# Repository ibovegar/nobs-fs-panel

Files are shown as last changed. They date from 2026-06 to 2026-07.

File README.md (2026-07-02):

# Nobs Panel

A build-it-yourself switch panel for flight simulators: **8 toggle switches** wired to an
**Arduino Nano ESP32**. It plugs in over USB and shows up as a standard game controller (HID
gamepad) named **"Nobs Panel"**, recognised directly by MSFS and the Nobs app with no drivers to
install.

SW1–SW6 are 2-position (ON-ON) and SW7–SW8 are 3-position (ON-OFF-ON); each switch's two outer
terminals are reported as two buttons, for **16 buttons** total.

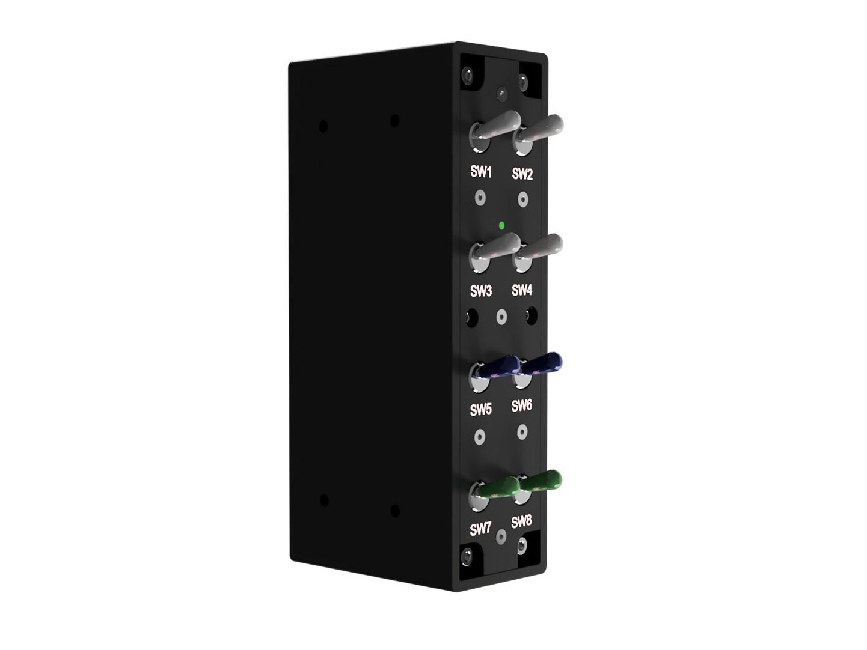
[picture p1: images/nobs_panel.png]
Nobs Panel


## Design Philosophy

**This panel is built for tactile, no-fuss control**: real mechanical toggles instead of a
touchscreen or software panel, so you always know a switch's state by feel alone, no looking
needed, which also makes it VR-friendly. Because it enumerates as a plain USB game controller,
there's nothing to install and nothing that can fall out of sync with a sim update:
* **Physical Switches, Not Software:** Every switch is a genuine toggle with a positive snap, so
  flipping it is unambiguous even without looking.
* **Driver-Free by Design:** The board presents itself as a standard HID gamepad, so MSFS and the
  Nobs app recognise it the moment it's plugged in.

## Docs

- **[Build instructions](docs/build-instructions.md)**: step-by-step assembly, photos included.
- **[Which wire goes where](docs/arduino-esp-32-wiring.md)**: the button + pin map. For a visual
  reference alongside it, see the [wiring diagram](docs/wiring-diagram.pdf).
- **[Loading the firmware](firmware/arduino_eps32_nano/README.md)**: first-time flashing and
  re-flashing, step by step.
- **[Left-mount variant](firmware/arduino_eps32_nano_left/README.md)**: a version wired for mounting
  on the **left** side of a frame, with its own [wiring map](docs/arduino-esp-32-wiring-left.md). See
  [Mounting orientation](#mounting-orientation-left-or-right) below.
- **[Setting the device ID & name](docs/board-identity.md)**: how the board names itself, how to
  rename it, and how to run several panels at once (each gets its own ID + name).
- **[Bill of materials](docs/bill-of-materials.md)**: parts list.

## Mounting orientation (left or right)

The Nobs panels are designed to mount to a 40x80 T-slot aluminium extrusion rig (e.g. a Track
Racer TR160), around the central profile assembly that holds the flight yoke or steering wheel:
**Nobs Panel** mounts to the left of the assembly, **Nobs Approach** to the right, and **Nobs
Autopilot** on top.

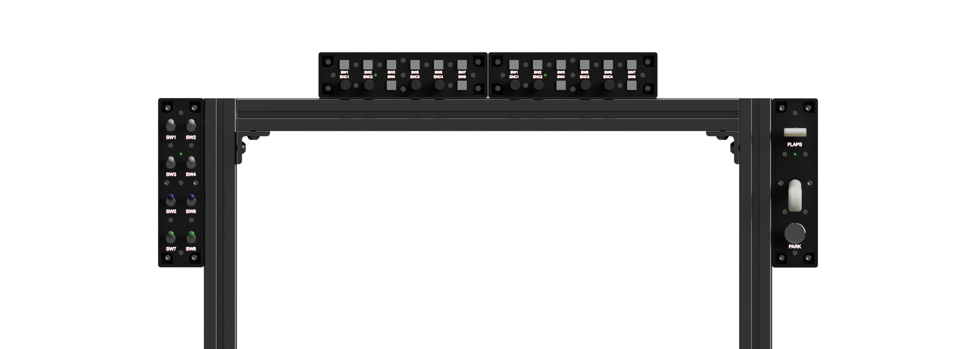
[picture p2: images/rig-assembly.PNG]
Rig assembly


The panel comes in two wiring variants so it reads correctly whichever side of a track-racer
T-profile aluminium frame you mount it on:

- **Right mount (standard):** firmware in [`firmware/arduino_eps32_nano/`](firmware/arduino_eps32_nano/),
  wiring in [arduino-esp-32-wiring.md](docs/arduino-esp-32-wiring.md).
- **Left mount:** firmware in [`firmware/arduino_eps32_nano_left/`](firmware/arduino_eps32_nano_left/),
  wiring in [arduino-esp-32-wiring-left.md](docs/arduino-esp-32-wiring-left.md).

The two are identical apart from the switch-to-pin map, which the left variant mirrors for a left
mount: the switch order is reversed (SW1/SW2 swap pin groups with SW8/SW7, and the middle four
mirror too: SW3 with SW6, SW4 with SW5), and each switch's two terminals are swapped so its up/down
isn't inverted by the rotated mount. Both present the same 16 buttons. Pick the firmware and wiring
map that match how you mounted the panel, and don't mix one variant's firmware with the other's
wiring.

Because a left and a right panel can sit in the same rig, they ship with **different default USB
IDs** from the panel's ID block so the simulator never mixes up their bindings: the right (standard)
variant is the 1st panel instance (`80F0` / "Nobs Panel"), the left variant is the 2nd
(`80F1` / "Nobs Panel 2"). See [Setting the device ID & name](#setting-the-device-id--name-in-brief)
and [docs/board-identity.md](docs/board-identity.md) for the full scheme.

## Nobs FS Companion App

The [**Nobs FS app**](https://github.com/ibovegar/nobs-fs-app) is the companion application for
communicating with and configuring this panel. It automatically detects the Nobs Panel by its USB
identity (VID `303A` / PID `80F0`), so the right device is selected even when other game
controllers are connected.

Use it to:
* **Verify wiring & test inputs:** watch every switch register live as you flip it, handy for
  confirming the build before binding anything in the sim.
* **Track multiple panels:** the Devices page lets you add extra instances of the panel, each with
  its own ID and name (see [Setting the device ID & name](#setting-the-device-id--name-in-brief)
  below), so the app and the sim can tell them apart.

See the app repository for installation and usage details: <https://github.com/ibovegar/nobs-fs-app>

## Setting the device ID & name (in brief)

The board's name and USB product ID aren't compiled in; they're stored on the board, so the same
firmware can be set up as any Nobs profile. Out of the box this is **"Nobs Panel"** (`303A` /
`80F0`). To change it, the configuration app sends a single line over the board's serial port:

```
SET_ID:80F0:Nobs Panel
```

The board saves the new name + ID, replies `OK:80F0:Nobs Panel`, and reboots so it takes effect
(`GET_ID` reads back the current values). For multiple panels, give each one the next ID in the
block, e.g. `SET_ID:80F1:Nobs Panel 2`. Full details, including the Windows name-cache refresh,
are in **[docs/board-identity.md](docs/board-identity.md)**.

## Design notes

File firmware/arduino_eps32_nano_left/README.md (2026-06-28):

# Nobs Panel: Arduino Nano ESP32 Firmware (left-mount variant)

This is the **left-mount** version of the Nobs Panel firmware, for a panel mounted on the **left**
side of a track-racer T-profile aluminium frame. It is identical to the standard (right-mount)
firmware in [`../arduino_eps32_nano/`](../arduino_eps32_nano/) except for the switch-to-pin map:
SW1/SW2 and SW7/SW8 trade pin groups so the switches read in the correct order from the left,
SW3–SW6 are unchanged. It exposes the same **16 buttons**. Wiring is in
[`docs/arduino-esp-32-wiring-left.md`](../../docs/arduino-esp-32-wiring-left.md).

Because a left panel is built to share a rig with a standard (right) panel, this firmware defaults
to the **2nd panel instance** of the panel PID block: PID **`80F1`** / name **"Nobs Panel 2"**
(the standard panel is instance 1, `80F0` / "Nobs Panel"). The two then never collide, so the
simulator keeps their bindings separate. Add it on the Nobs app's **Devices** page with the **+**
on the panel product, which tracks it as the 2nd panel. (If a left panel is your *only* panel, you
can move it onto `80F0` / "Nobs Panel" with the config app.) See
[`docs/board-identity.md`](../../docs/board-identity.md) for the full ID scheme.

> Flash this sketch only if you built the panel for a **left** mount. For a standard (right) mount,
> use [`../arduino_eps32_nano/`](../arduino_eps32_nano/) instead. The two are not interchangeable:
> they expect the switches wired to different pins.

> 👍 Everything you need is in this folder. You don't edit any Arduino files. Keep
> [`build_opt.h`](./build_opt.h) next to the sketch: the IDE uses it automatically, and the build
> fails on purpose without it. Tested with the Arduino ESP32 board package `2.0.18-arduino.5`.

## One-time setup

1. Install the **Arduino IDE** (free, from arduino.cc).
2. Add the board: **Tools → Board → Boards Manager…**, search **Arduino ESP32 Boards**, click
   **Install** (big download). Then pick **Tools → Board → Arduino ESP32 Boards → Arduino Nano ESP32**.
3. In **Tools**, set **USB Mode → `Normal mode (TinyUSB)`** and **Pin Numbering → `By Arduino pin (default)`**.

> If the board install fails ("platform not installed"), close the IDE, reopen it **as
> administrator**, and try again.

## Flashing the first time

1. Open [`arduino_eps32_nano_left.ino`](./arduino_eps32_nano_left.ino) in the Arduino IDE.
2. Plug in the board with a **data** USB cable (not charge-only), straight into the PC.
3. Click **Upload** (the round arrow).

On a fresh board this just works. 🎉 When it's done, the board reconnects as **"Nobs Panel 2"** and
the app picks it up automatically.

## Re-flashing (after firmware is already on it)

This is **different**, and expected. Once the firmware is running, the board reports a custom USB
ID and no longer auto-enters upload mode, so a normal Upload fails with:

```
No DFU capable USB device available — exit status 74
```

Put the board into **update mode** by hand first:

1. Press the **RESET** button **twice, quickly** (like a mouse double-click, ~0.3–0.5 s apart).
2. You're in update mode when the **green LED breathes slowly in and out and stays there**.
   A quick red→blue→green flash that stops is just a normal reset; try the double-tap again.
3. With the green breathing, click **Upload** right away.
4. When it finishes, press **RESET once** to start the firmware.

> **If upload still can't find the board:** it's almost always the **cable or USB port**. Swap to
> a known-good data cable and a different port (this is the most common cause). The double-tap
> timing is the other one; keep trying the rhythm.

## Check it works

- **Nobs app:** the panel is detected automatically; flip switches and watch them light up.
- **Windows:** press `Win`, type **Set up USB game controllers**, open the device's **Properties**,
  and flip switches to see the 16 buttons react.

## Changing the board's name / ID

The name and product ID aren't compiled in; they're stored on the board, so the same firmware can
become any Nobs profile. Out of the box this variant is **"Nobs Panel 2"** (`303A` / `80F1`). The
configuration app changes it over the board's serial port. See
[`docs/board-identity.md`](../../docs/board-identity.md) for how that works and the full profile list.

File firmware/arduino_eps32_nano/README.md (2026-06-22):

# Nobs Panel: Arduino Nano ESP32 Firmware

This is the program (the "firmware") that runs on an **Arduino Nano ESP32** and turns it into a
USB game controller for Microsoft Flight Simulator. Once loaded, the board shows up to your PC and
the Nobs app as **"Nobs Panel"** with **16 buttons**: the 8 toggle switches, two buttons each
(one per position). Wiring is in [`docs/arduino-esp-32-wiring.md`](../../docs/arduino-esp-32-wiring.md).

> 👍 Everything you need is in this folder. You don't edit any Arduino files. Keep
> [`build_opt.h`](./build_opt.h) next to the sketch: the IDE uses it automatically, and the build
> fails on purpose without it. Tested with the Arduino ESP32 board package `2.0.18-arduino.5`.

## One-time setup

1. Install the **Arduino IDE** (free, from arduino.cc).
2. Add the board: **Tools → Board → Boards Manager…**, search **Arduino ESP32 Boards**, click
   **Install** (big download). Then pick **Tools → Board → Arduino ESP32 Boards → Arduino Nano ESP32**.
3. In **Tools**, set **USB Mode → `Normal mode (TinyUSB)`** and **Pin Numbering → `By Arduino pin (default)`**.

> If the board install fails ("platform not installed"), close the IDE, reopen it **as
> administrator**, and try again.

## Flashing the first time

1. Open [`arduino_eps32_nano.ino`](./arduino_eps32_nano.ino) in the Arduino IDE.
2. Plug in the board with a **data** USB cable (not charge-only), straight into the PC.
3. Click **Upload** (the round arrow).

On a fresh board this just works. 🎉 When it's done, the board reconnects as **"Nobs Panel"** and
the app picks it up automatically.

## Re-flashing (after firmware is already on it)

This is **different**, and expected. Once the firmware is running, the board reports a custom USB
ID and no longer auto-enters upload mode, so a normal Upload fails with:

```
No DFU capable USB device available — exit status 74
```

Put the board into **update mode** by hand first:

1. Press the **RESET** button **twice, quickly** (like a mouse double-click, ~0.3–0.5 s apart).
2. You're in update mode when the **green LED breathes slowly in and out and stays there**.
   A quick red→blue→green flash that stops is just a normal reset; try the double-tap again.
3. With the green breathing, click **Upload** right away.
4. When it finishes, press **RESET once** to start the firmware.

> **If upload still can't find the board:** it's almost always the **cable or USB port**. Swap to
> a known-good data cable and a different port (this is the most common cause). The double-tap
> timing is the other one; keep trying the rhythm.

## Check it works

- **Nobs app:** the panel is detected automatically; flip switches and watch them light up.
- **Windows:** press `Win`, type **Set up USB game controllers**, open the device's **Properties**,
  and flip switches to see the 16 buttons react.

## Changing the board's name / ID

The name and product ID aren't compiled in; they're stored on the board, so the same firmware can
become any Nobs profile. Out of the box it's **"Nobs Panel"** (`303A` / `80F0`). The configuration
app changes it over the board's serial port. See
[`docs/board-identity.md`](../../docs/board-identity.md) for how that works and the full profile list.

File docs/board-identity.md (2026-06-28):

# How the Board Names Itself (and How to Rename It)

This page explains, in plain language, how a Nobs board tells your PC who it is, and how you can
change that without re-installing the firmware. You don't need to understand any of this to use
the panel; it's here for the curious and for anyone setting up more than one box.

## The short version

- Every Nobs box appears to your PC as a USB game controller with a **name** (like "Nobs Panel")
  and an **ID number** (called a *Product ID*, or **PID**).
- That name and ID are **not baked into the firmware**. The board remembers them in its own
  memory, so the *same* firmware can be set up as a panel, an autopilot, or an approach box.
- Out of the box, this board is **"Nobs Panel"**. You can change it later with the configuration
  app, no re-flashing needed.

## Why each box needs its own name and ID

If you own more than one Nobs box, this matters. Microsoft Flight Simulator keeps a separate set
of button bindings for each controller, but it tells controllers apart by their **ID number**.

If two boxes shared the same ID, the simulator would treat them as the same device and **mix up
their button assignments**. Giving each box its own ID (and a clear name) keeps their controls
neatly separated, so plugging in a second or third box never disturbs the first.

Here are the standard profiles. Each product owns a small **block of IDs** so you can have several
of the same type (see below):

| If the box is a… | It should be named… | ID block |
| :--- | :--- | :--- |
| Panel | Nobs Panel | `80F0`–`80F3` |
| Autopilot | Nobs Autopilot | `80F4`–`80F7` |
| Approach | Nobs Approach | `80F8`–`80FB` |

(They all share the same *vendor* ID, `303A`; that part never changes.)

## Running several of the same type

You can use more than one of the same module (say two panels) at the same time. The catch is
they must **not** look identical to the PC, or the simulator mixes up their bindings. So each one
gets its own ID and name from its product's block:

| | Name | ID |
| :-- | :-- | :-- |
| 1st panel | Nobs Panel | `80F0` |
| 2nd panel | Nobs Panel 2 | `80F1` |
| 3rd panel | Nobs Panel 3 | `80F2` |

The first one keeps the plain name and the block's first ID (its out-of-box default). For each
extra one, give it the next ID and a numbered name with the rename step below, e.g. send
`SET_ID:80F1:Nobs Panel 2` to the second panel. In the Nobs app, open **Devices** and press **+**
on that product to start tracking the extra module. The simulator then sees "Nobs Panel" and "Nobs
Panel 2" as two separate controllers with independent bindings.

> **Left-mount panels:** the [left-mount firmware variant](../firmware/arduino_eps32_nano_left/README.md)
> is built to share a rig with a standard (right) panel, so it already ships on the **2nd** panel
> instance (`80F1` / "Nobs Panel 2") rather than `80F0`. A left + right pair therefore works out of
> the box with no renaming. If a left panel is your only panel, you can move it onto `80F0` /
> "Nobs Panel" with the rename step below.

## How to rename a board

The configuration app does this for you. Behind the scenes it just sends the board one short line
of text over its connection, for example:

```
SET_ID:80F0:Nobs Panel
```

That reads as: *"Set your ID to `80F0` and your name to `Nobs Panel`."* The board then:

1. **Saves** the new name and ID into its own memory.
2. **Confirms** it received them.
3. **Restarts itself** and comes back wearing the new name.

That restart is normal and only takes a second. The reason it's needed: a board can only announce
its identity to the PC at the moment it powers on, so it has to reboot for a new name to take
effect.

> 💡 To check what a board is currently called, the app can ask it with `GET_ID`, and the board
> replies with its stored name and ID.

## If Windows still shows the old name

Windows likes to remember names, so occasionally after a rename it'll keep showing the **old** one
in its game-controller list or in the simulator. If that happens, nudge it to take a fresh look:

1. Leave the board plugged in.
2. Right-click the **Start** button → open **Device Manager**.
3. Open the **Human Interface Devices** group.
4. Right-click your controller → **Uninstall device**.
5. Unplug the USB cable, wait a couple of seconds, and plug it back in.

Windows will then read the board's name again from scratch and show the updated one.

## Related pages

- [Which wire goes where](./arduino-esp-32-wiring.md): the button and pin map.
- [Loading the firmware](../firmware/arduino_eps32_nano/README.md): step-by-step setup, including
  the more technical details of how the identity is stored.

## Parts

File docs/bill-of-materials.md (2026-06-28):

# Bill of Materials (Shopping List)

This is the full shopping list for building one Nobs Panel: every part you need, from the
electronics to the screws. The "Manufacturer / Part Number" column lists the exact parts we used,
linked to their Mouser listing, so you can search for them or find equivalents.

A few friendly notes before you start buying:

- **Exact parts aren't mandatory.** The switches, terminal blocks, and stripboard can be swapped
  for similar parts you like or already have. The part numbers here are just what's known to work.
- **The enclosure parts (section 2) are 3D printed**: you print them yourself from the files in
  the `models/` folder, or have a print service make them.
- Quantities are for **one** panel.

## Core Electronics & Switches

| Item # | Qty | Component Description | Manufacturer / Part Number | Purpose / Application |
| :--- | :--- | :--- | :--- | :--- |
| **1.1** | 1 | Arduino Nano ESP32 (with headers) | [Arduino / ABX00083](https://no.mouser.com/ProductDetail/Arduino/ABX00083) | Main microcontroller (ESP32-S3, USB HID, VID 0x303A / PID 0x80F0) |
| **1.2** | 6 | SPDT Toggle Switch, On-On (2-position) | [Apem / 636H-2](https://no.mouser.com/ProductDetail/Apem/636H-2) | SW1–SW6 |
| **1.3** | 2 | SPDT Toggle Switch, On-Off-On (3-position) | [Apem / 639H-2](https://no.mouser.com/ProductDetail/Apem/639H-2) | SW7–SW8 |
| **1.4** | 1 | Stripboard, 50 × 80 mm | [BusBoard Prototype Systems / ST1](https://no.mouser.com/ProductDetail/BusBoard-Prototype-Systems/ST1) | Controller board carrier for the Arduino, pin headers, and terminal blocks |
| **1.5** | 2 | Female Pin Header Socket, 26-position, 2.54 mm pitch | [3M Electronic Solutions Division / 929850-01-26-RA](https://no.mouser.com/ProductDetail/3M-Electronic-Solutions-Division/929850-01-26-RA) | Sockets soldered to the stripboard to seat the Arduino Nano ESP32 |
| **1.6** | 2 | Fixed Terminal Block, 6-position, 2.54 mm pitch | [GCT / TBC05-06-1-G-G](https://no.mouser.com/ProductDetail/GCT/TBC05-06-1-G-G) | Screw-down wiring for the switch signal and ground wires |
| **1.7** | 1 | 3 mm Green LED, Diffused, 2.2 V | [Lumex / SSL-LX30FT4GD](https://no.mouser.com/ProductDetail/Lumex/SSL-LX30FT4GD?qs=7jmq9uQgtYG4HR2h%252BlgbMw%3D%3D) | Front-plate status indicator |
| **1.8** | 1 | 120 Ω Resistor, 1/4 W, ±1%, Metal Film | [KOA Speer / MFS1/4DCT52R1200F](https://no.mouser.com/ProductDetail/KOA-Speer/MFS1-4DCT52R1200F?qs=ddCg%252BR5cWn20oJHZLuYO%2FQ%3D%3D) | Current-limiting resistor for the status LED |
| **1.9** | 2 | Toggle Switch Cap, Bat Lever, Green | [NKK Switches / AT434F](https://no.mouser.com/ProductDetail/NKK-Switches/AT434F?qs=O05gvr8fLT3nXnSEPt0k3g%3D%3D) | Color-coded cap for toggle switches |
| **1.10** | 2 | Toggle Switch Cap, Bat Lever, Red | [NKK Switches / AT434C](https://no.mouser.com/ProductDetail/NKK-Switches/AT434C?qs=O05gvr8fLT2riUxsIoEfkQ%3D%3D) | Color-coded cap for toggle switches |
| **1.11** | 4 | Toggle Switch Cap, Bat Lever, White | [NKK Switches / AT434B](https://no.mouser.com/ProductDetail/NKK-Switches/AT434B?qs=O05gvr8fLT2J5h7R71L7Aw%3D%3D) | Color-coded cap for toggle switches |

## Structural & Enclosure Hardware

| Item # | Qty | Component Description | Manufacturer / Part Number | Purpose / Application |
| :--- | :--- | :--- | :--- | :--- |
| **2.1** | 1 | Enclosure Top | 3D Printed (`models/enclosure_top.step`) | Main upper housing shell |
| **2.2** | 1 | Enclosure Bottom | 3D Printed (`models/enclosure_bottom.step`) | Main lower housing base, carries the controller board |
| **2.3** | 1 | Mounting Plate | 3D Printed (`models/nobs_panel_mounting_plate.step`) | Carries the 8 toggle switches |
| **2.4** | 1 | Front Plate | 3D Printed (`models/nobs_panel_frontpanel.step`) | Visual faceplate with switch labels |
| **2.5** | 10 | M4 Heat-Set Insert | [SI (PennEngineering) / IUTB-M4](https://no.mouser.com/ProductDetail/SI/IUTB-M4) | Threaded anchors moulded into the enclosure top/bottom |
| **2.6** | 11 | M3 Heat-Set Insert | [SI (PennEngineering) / IUTB-M3](https://no.mouser.com/ProductDetail/SI/IUTB-M3) | Threaded anchors moulded into the mounting plate and front plate |
| **2.7** | 4 | M4 × 0.7, 30 mm Socket-Head Screw | — | Clamps the enclosure top and bottom halves together |
| **2.8** | 6 | M4 × 0.7, 10 mm Socket-Head Screw | — | Fastens the mounting plate to the rear of the enclosure bottom |
| **2.9** | 4 | M3 × 0.5, 8 mm Pan-Head Screw | — | Fastens the controller board to its standoffs in the enclosure bottom |
| **2.10** | 7 | M3 × 0.5, 8 mm Countersunk Screw | — | Fastens the front plate to the mounting plate, and the assembly to the enclosure |

## Connectors & Wiring

| Item # | Qty | Component Description | Manufacturer / Part Number | Purpose / Application |
| :--- | :--- | :--- | :--- | :--- |
| **3.1** | 1 | USB-C to USB-A Cable, 1.5 m to 2 m, data-sync capable | — | Connects the Arduino Nano ESP32 to your PC |
| **3.2** | 1 | Heat Shrink Tubing Assortment Pack, 1.5 mm to 3.5 mm diameters | — | Insulates soldered connections on the switch terminals |

## Tools Recommended for Assembly (Not in BOM Cost)

* **Soldering Iron & Lead-Free Rosin-Core Solder:** for attaching wires to the switch terminals
  and seating the pin headers/terminal blocks on the stripboard.
* **Wire Strippers & Flush Cutters:** for prepping the signal and ground wires.
* **Soldering Iron / Insert Tool for Heat-Set Inserts:** for pressing the brass inserts squarely
  into the 3D-printed parts.
* **Multimeter:** for testing continuity and checking for short circuits across the common ground
  loop before plugging into USB power.

## Project Costs

Rough cost estimate for a single panel, in USD. These are ballpark figures only, actual prices
vary significantly by supplier, region, and quantity, and **exclude shipping and taxes**. Several
items (heat-set inserts, screws) are sold in multi-build packs, so the per-build cost is lower if
you build more than one or already have them on hand.

| Category | Items | Estimated Cost |
| :--- | :--- | ---: |
| Microcontroller | Arduino Nano ESP32 (genuine; clones are cheaper) | $20 – $28 |
| Switches | 6 × Apem 636H-2 + 2 × Apem 639H-2 | $40 – $65 |
| Board & connectors | Stripboard, 2 × pin headers, 2 × terminal blocks, status LED | $10 – $15 |
| Fasteners | Heat-set inserts (21) and M3/M4 screws (21) | $10 – $18 |
| Enclosure (3D printed) | Filament for top, bottom, mounting plate, front plate | $5 – $15 |
| Connectors & wiring | USB-C cable, heat-shrink tubing pack | $8 – $15 |
| **Total** | | **≈ $93 – $156** |

> **Notes:**
> * The **enclosure** assumes you print the parts yourself (filament cost only). Ordering them
>   from a print service will add roughly $20 – $50.
> * This estimate doesn't include hookup wire, since it's usually bought once in bulk and reused
>   across builds.
> * Bulk/pack purchasing of the inserts, screws, and heat-shrink tubing spreads their cost across
>   multiple builds, lowering the effective per-panel total.

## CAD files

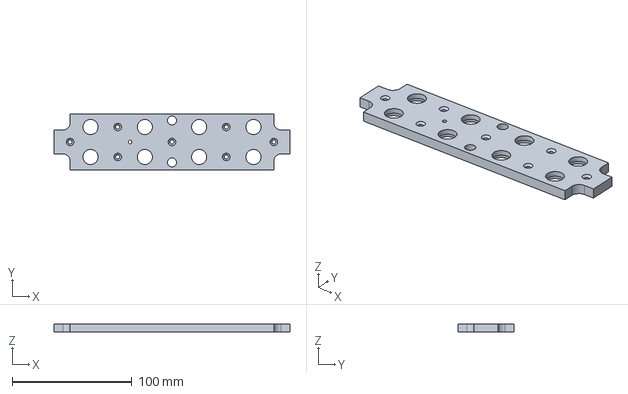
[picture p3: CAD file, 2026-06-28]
models/nobs_panel_frontpanel.step
197.0 x 47.0 x 7.00 mm

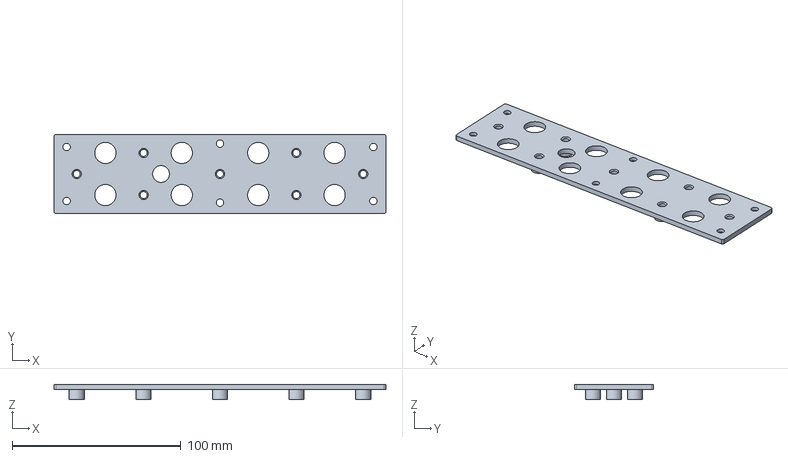
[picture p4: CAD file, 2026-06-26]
models/nobs_panel_mounting_plate.step
197.0 x 47.0 x 9.00 mm

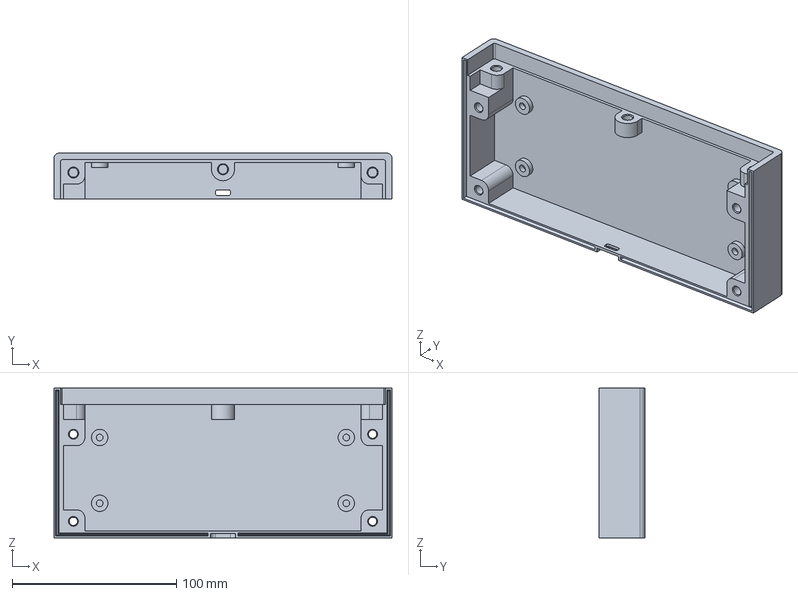
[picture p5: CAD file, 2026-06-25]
models/enclosure_top.step
205.6 x 27.8 x 91.0 mm

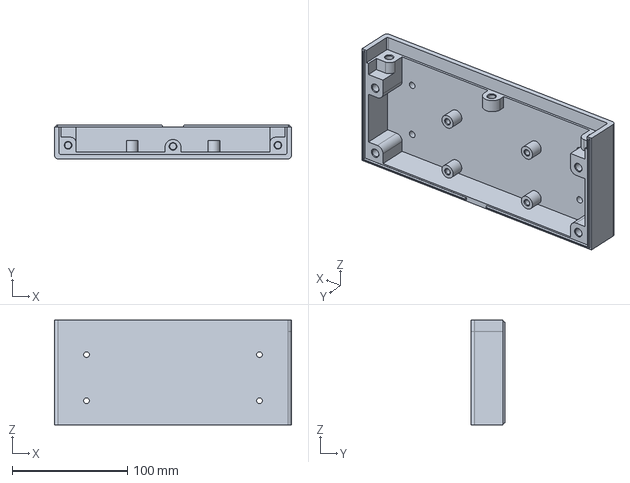
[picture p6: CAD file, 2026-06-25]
models/enclosure_bottom.step
205.6 x 29.3 x 91.0 mm

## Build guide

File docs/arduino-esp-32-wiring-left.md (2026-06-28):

# Wiring Map (Left Mount): Which Wire Goes Where

This is the wiring table for the **left-mount** version of the panel, mounted on the **left** side
of a track-racer T-profile aluminium frame. It pairs with the left firmware in
[`firmware/arduino_eps32_nano_left/`](../firmware/arduino_eps32_nano_left/). For a standard (right)
mount, use [arduino-esp-32-wiring.md](arduino-esp-32-wiring.md) and its firmware instead.

Compared with the standard wiring, the panel is **mirrored for a left mount**, which changes the
map in two ways:

1. **The switch order is reversed** so the switches read in the correct order from the left: SW1/SW2
   trade their pin groups with SW8/SW7, and the middle four mirror too (**SW3 swaps with SW6, SW4
   swaps with SW5**).
2. **Each switch's two positions are flipped.** The switch sits rotated in a left mount, so its Pin
   1 and Pin 3 terminals map to the opposite position (and HID button) than on the standard mount.
   Without this the switches would read upside down (flipping up shows as down).

The board pin each terminal connects to is the actionable column and is the same as how the switch
is physically wired; the switch types and the set of 16 HID buttons are unchanged.

This button box has **8 toggle switches**: SW1–SW6 are **ON-ON** (2-position) and SW7–SW8 are
**ON-OFF-ON** (3-position, with the center position doing nothing). Every switch has three
terminals: the two outer terminals (pin 1 and pin 3) each go to a signal pin, and the center
terminal (pin 2) goes to **GND**.

**How to read a row:** find the switch (e.g. "SW1"), look at which terminal it is ("Pin 1"), then
run a wire from that terminal to the pin listed in the board's column. Pin names like `D13` or
`A0` are printed on the board itself. Every switch's center terminal (pin 2) connects to **GND**
(ground), see the last row.

The "Virtual HID Button" column is just for reference: it's the button number the sim sees when
you flip that switch into that position. You don't wire anything for it.

> 💡 Each switch terminal has one wire to its signal pin (from this table) and the center terminal
> wires to **GND**. No resistors or extra parts needed; the firmware handles that.

| Component Group | Component Label | Hardware Connection | Arduino Nano ESP32 Pin | Virtual HID Button | Action Type |
| :--- | :--- | :--- | :--- | :--- | :--- |
| **SW1** (ON-ON) | Switch 1 | Pin 1 Terminal | **D8** | Button 2 | Position 2 |
| | Switch 1 | Pin 3 Terminal | **D7** | Button 1 | Position 1 |
| **SW2** (ON-ON) | Switch 2 | Pin 1 Terminal | **D6** | Button 4 | Position 2 |
| | Switch 2 | Pin 3 Terminal | **D5** | Button 3 | Position 1 |
| **SW3** (ON-ON) | Switch 3 | Pin 1 Terminal | **D10** | Button 6 | Position 2 |
| | Switch 3 | Pin 3 Terminal | **D9** | Button 5 | Position 1 |
| **SW4** (ON-ON) | Switch 4 | Pin 1 Terminal | **D12** | Button 8 | Position 2 |
| | Switch 4 | Pin 3 Terminal | **D11** | Button 7 | Position 1 |
| **SW5** (ON-ON) | Switch 5 | Pin 1 Terminal | **A6** | Button 10 | Position 2 |
| | Switch 5 | Pin 3 Terminal | **A7** | Button 9 | Position 1 |
| **SW6** (ON-ON) | Switch 6 | Pin 1 Terminal | **A4** | Button 12 | Position 2 |
| | Switch 6 | Pin 3 Terminal | **A5** | Button 11 | Position 1 |
| **SW7** (ON-OFF-ON) | Switch 7 | Pin 1 Terminal | **A2** | Button 14 | Position 2 |
| | Switch 7 | Pin 3 Terminal | **A3** | Button 13 | Position 1 |
| **SW8** (ON-OFF-ON) | Switch 8 | Pin 1 Terminal | **A0** | Button 16 | Position 2 |
| | Switch 8 | Pin 3 Terminal | **A1** | Button 15 | Position 1 |
| **Ground Loop** | All Switches | Pin 2 / Center Terminals | **GND** | *None* | System Ground |
| **Status LED** | Status LED | Anode, via 120 Ω resistor | **D4** | *None* | Boot/Connect Status |
| | Status LED | Cathode | **GND** | *None* | Boot/Connect Status |

> 💡 **Status LED:** wired with a 120 Ω current-limiting resistor from **D4** to **GND**. It blinks
> while the board is booting/waiting for USB enumeration, and lights steady once the host PC has
> enumerated it. (Same as the standard mount — the LED isn't affected by the left-mount pin swap.)

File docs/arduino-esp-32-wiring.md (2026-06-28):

# Wiring Map: Which Wire Goes Where

This table tells you which pin on the board each wire connects to, for the **Arduino Nano ESP32**.

> This is the **standard (right-mount)** wiring, paired with the firmware in
> [`firmware/arduino_eps32_nano/`](../firmware/arduino_eps32_nano/). If you are building the panel
> for a **left** mount, use [arduino-esp-32-wiring-left.md](arduino-esp-32-wiring-left.md) and its
> left firmware instead.

This button box has **8 toggle switches**: SW1–SW6 are **ON-ON** (2-position) and SW7–SW8 are
**ON-OFF-ON** (3-position, with the center position doing nothing). Every switch has three
terminals: the two outer terminals (pin 1 and pin 3) each go to a signal pin, and the center
terminal (pin 2) goes to **GND**.

**How to read a row:** find the switch (e.g. "SW1"), look at which terminal it is ("Pin 1"), then
run a wire from that terminal to the pin listed in the board's column. Pin names like `D13` or
`A0` are printed on the board itself. Every switch's center terminal (pin 2) connects to **GND**
(ground), see the last row.

The "Virtual HID Button" column is just for reference: it's the button number the sim sees when
you flip that switch into that position. You don't wire anything for it.

> 💡 Each switch terminal has one wire to its signal pin (from this table) and the center terminal
> wires to **GND**. No resistors or extra parts needed; the firmware handles that.

| Component Group | Component Label | Hardware Connection | Arduino Nano ESP32 Pin | Virtual HID Button | Action Type |
| :--- | :--- | :--- | :--- | :--- | :--- |
| **SW1** (ON-ON) | Switch 1 | Pin 1 Terminal | **A0** | Button 1 | Position 1 |
| | Switch 1 | Pin 3 Terminal | **A1** | Button 2 | Position 2 |
| **SW2** (ON-ON) | Switch 2 | Pin 1 Terminal | **A2** | Button 3 | Position 1 |
| | Switch 2 | Pin 3 Terminal | **A3** | Button 4 | Position 2 |
| **SW3** (ON-ON) | Switch 3 | Pin 1 Terminal | **A4** | Button 5 | Position 1 |
| | Switch 3 | Pin 3 Terminal | **A5** | Button 6 | Position 2 |
| **SW4** (ON-ON) | Switch 4 | Pin 1 Terminal | **A6** | Button 7 | Position 1 |
| | Switch 4 | Pin 3 Terminal | **A7** | Button 8 | Position 2 |
| **SW5** (ON-ON) | Switch 5 | Pin 1 Terminal | **D12** | Button 9 | Position 1 |
| | Switch 5 | Pin 3 Terminal | **D11** | Button 10 | Position 2 |
| **SW6** (ON-ON) | Switch 6 | Pin 1 Terminal | **D10** | Button 11 | Position 1 |
| | Switch 6 | Pin 3 Terminal | **D9** | Button 12 | Position 2 |
| **SW7** (ON-OFF-ON) | Switch 7 | Pin 1 Terminal | **D8** | Button 13 | Position 1 |
| | Switch 7 | Pin 3 Terminal | **D7** | Button 14 | Position 2 |
| **SW8** (ON-OFF-ON) | Switch 8 | Pin 1 Terminal | **D6** | Button 15 | Position 1 |
| | Switch 8 | Pin 3 Terminal | **D5** | Button 16 | Position 2 |
| **Ground Loop** | All Switches | Pin 2 / Center Terminals | **GND** | *None* | System Ground |
| **Status LED** | Status LED | Anode, via 120 Ω resistor | **D4** | *None* | Boot/Connect Status |
| | Status LED | Cathode | **GND** | *None* | Boot/Connect Status |

> 💡 **Status LED:** wired with a 120 Ω current-limiting resistor from **D4** to **GND**. It blinks
> while the board is booting/waiting for USB enumeration, and lights steady once the host PC has
> enumerated it.

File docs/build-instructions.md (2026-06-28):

# Nobs Panel: Build Instructions

These are the hands-on build steps for the Nobs Panel: how to build the controller board, how to
assemble the enclosure, and how to verify it before binding in the sim. For the project overview,
parts list, and device identity, see the [main README](../README.md).

> For the pin map, see [arduino-esp-32-wiring.md](arduino-esp-32-wiring.md). For a visual
> reference alongside it, see the [wiring diagram](wiring_diagram.pdf).
>
> Mounting on the **left** side of a frame instead? Use the left-mount wiring map
> ([arduino-esp-32-wiring-left.md](arduino-esp-32-wiring-left.md)) and the matching left firmware
> throughout these steps. See [Mounting orientation](../README.md#mounting-orientation-left-or-right).

## Assembly Instructions

Here's how the panel goes together, in order, with a photo of the real build at each stage.
There's soldering involved, so take your time and work in a well-lit, ventilated spot. Don't
rush; it's much easier to get each joint right the first time than to fix it later.

### Building the Controller Board

The controller board is a stripboard carrying the Arduino, pin headers, and screw-terminal blocks
for all the switch wiring.

#### Phase 1: Bare Stripboard

<p align="center">
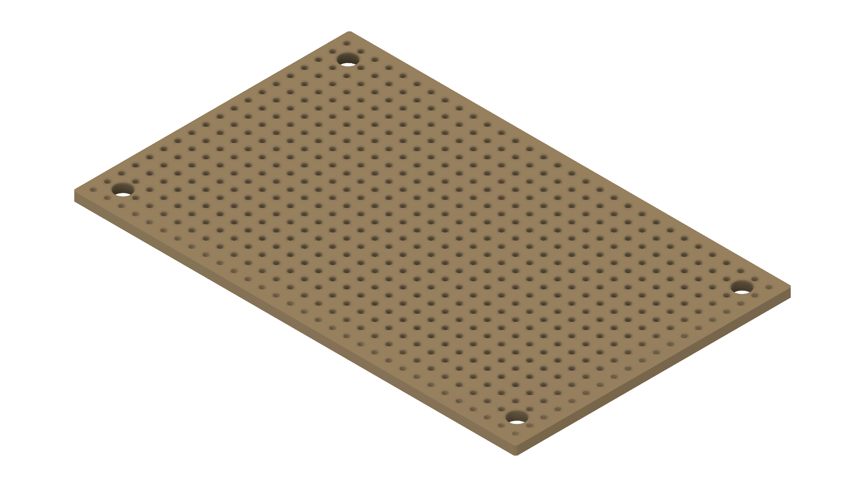
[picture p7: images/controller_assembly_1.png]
Bare stripboard
  
</p>
<br>

* **Start with the Stripboard:** This is the unmodified stripboard the rest of the controller
  board is built on. Copper strips run the full length of the board on the underside.

#### Phase 2: Mount the Pin Headers

<p align="center">
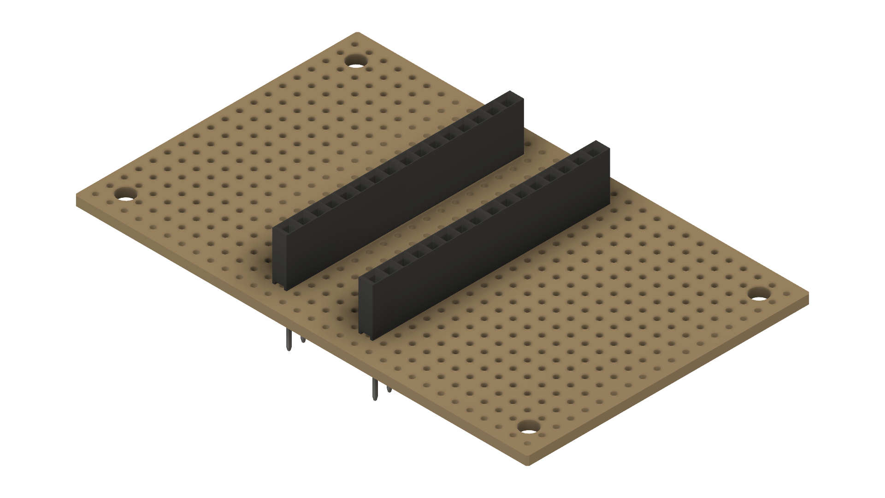
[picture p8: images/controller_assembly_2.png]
Pin headers mounted on the stripboard
  
</p>
<br>

* **Solder in the Pin Headers:** Mount the two female pin header rows that the Arduino Nano ESP32
  will plug into, spaced to match the Arduino's footprint.
* **Break the Strip Down the Middle:** The stripboard's copper strips run underneath both header
  rows, which would short the Arduino's top and bottom pin rows together. Cut or score each strip on the bottom side of the stripboard
  in the gap between the two header rows to break that connection before going further.

#### Phase 3: Mount the Terminal Blocks

<p align="center">
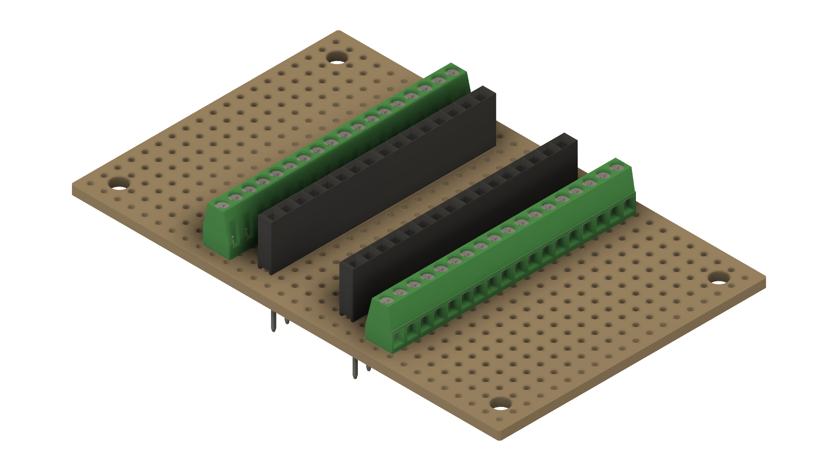
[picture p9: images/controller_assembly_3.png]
Terminal blocks mounted on the stripboard
  
</p>
<br>

* **Solder in the Terminal Blocks:** Mount the screw-terminal blocks alongside the pin headers.
  These are where each switch's signal and ground wires land, per the
  [wiring map](arduino-esp-32-wiring.md).

#### Phase 4: Add the Arduino Nano ESP32

<p align="center">
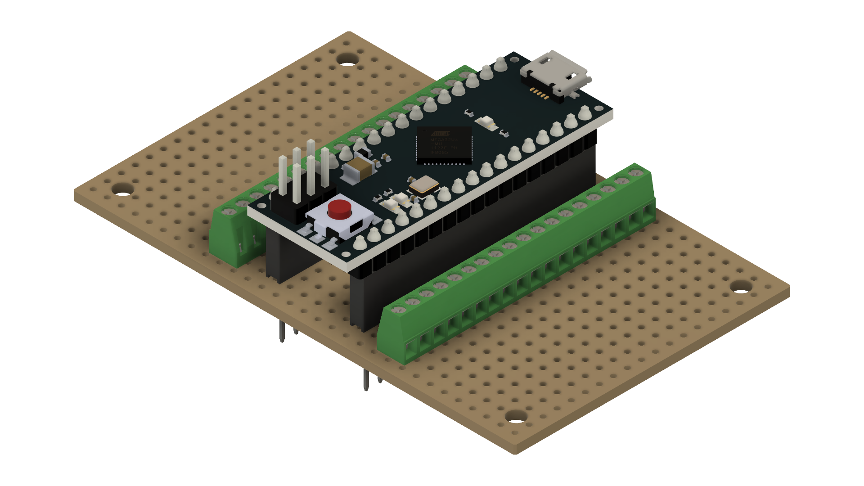
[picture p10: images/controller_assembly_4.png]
Arduino Nano ESP32 plugged into the controller board
  
</p>
<br>

* **Plug In the Arduino:** Seat the Arduino Nano ESP32 into the pin headers. The controller board
  is now complete and ready to go into the enclosure.

### Assembling the Enclosure

#### Phase 1: Heat-Set Inserts

<p align="center">
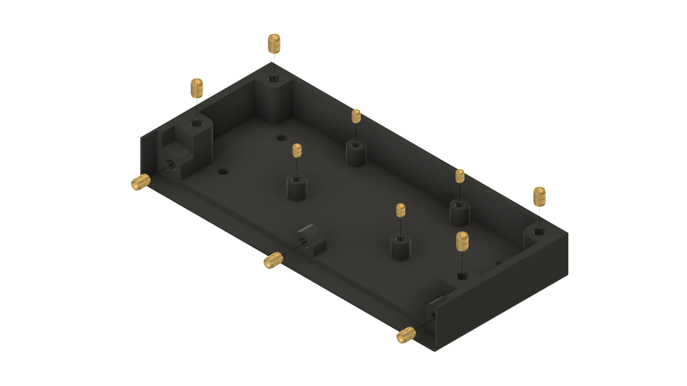
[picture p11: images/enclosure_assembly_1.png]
Heat-set inserts installed in the bottom enclosure
  
</p>
<br>

* **Press in the Inserts:** Using a soldering iron (or a dedicated insert tool) heated to the
  insert manufacturer's recommended temperature, press each heat-set insert squarely into its
  mounting post in the bottom enclosure. Go in slowly and keep the insert level: a crooked insert
  is the most common mistake here.
* **Do the Top Enclosure Too:** The top enclosure takes the same heat-set inserts in the same way.
  It isn't pictured separately; just repeat this step for it before moving on.

#### Phase 2: Mount the Controller Board to the Bottom Enclosure

<p align="center">
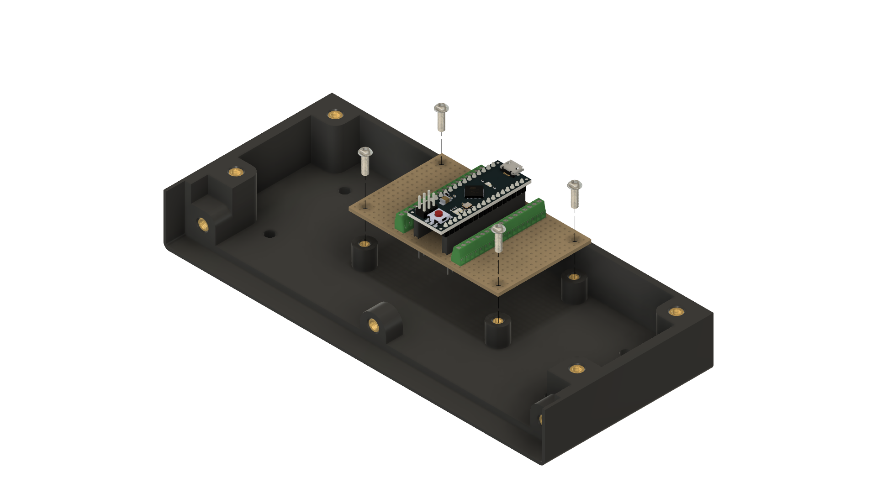
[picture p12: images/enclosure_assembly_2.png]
Controller board positioned over its mounting screws in the bottom enclosure
  
</p>
<br>

<p align="center">
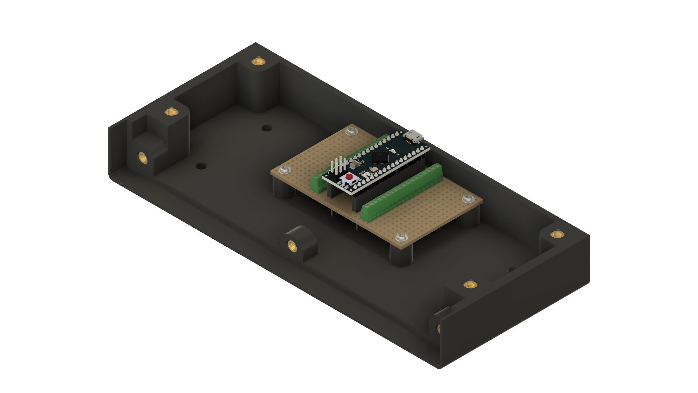
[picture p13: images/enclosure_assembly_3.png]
Controller board secured in the bottom enclosure
  
</p>
<br>

* **Secure the Controller Board:** Place the assembled controller board onto its standoffs in the
  bottom enclosure and fix it down with its mounting screws.

#### Phase 3: Heat-Set Inserts in the Mounting Plate

<p align="center">
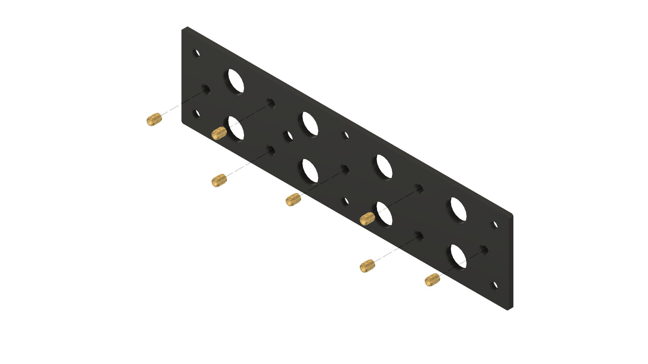
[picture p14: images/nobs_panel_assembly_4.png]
Heat-set inserts installed in the mounting plate
  
</p>
<br>

* **Press in the Inserts:** Press heat-set inserts into the mounting plate's posts the same way as
  the enclosure halves.

#### Phase 4: Mount the Switches to the Mounting Plate

<p align="center">
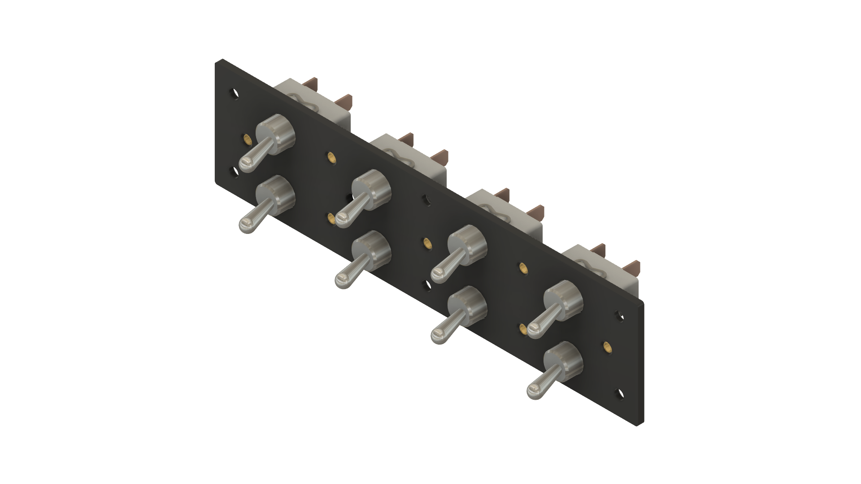
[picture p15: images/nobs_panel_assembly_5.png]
Toggle switches mounted in the mounting plate
  
</p>
<br>

* **Place the Switches:** Insert the 8 toggle switches into their cutouts in the mounting plate,
  in the layout shown, and secure each one with its included washer and hex nut, tightened firmly
  by hand. Avoid over-torquing the plastic.

#### Phase 5: Mount the Front Plate to the Mounting Plate

<p align="center">
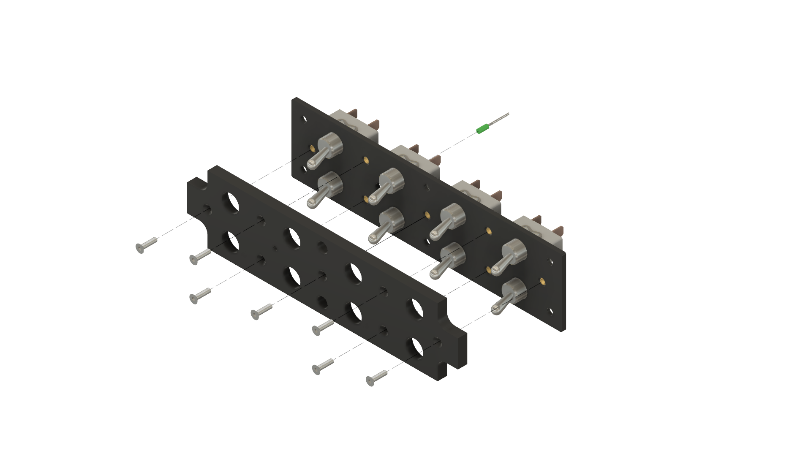
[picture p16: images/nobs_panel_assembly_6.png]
Front plate being secured over the mounted switches
  
</p>
<br>

* **Join Front Plate to Mounting Plate:** Align the front plate over the switches and secure it to
  the mounting plate with its mounting screws.

#### Phase 6: Mount the Assembly to the Enclosure

<p align="center">
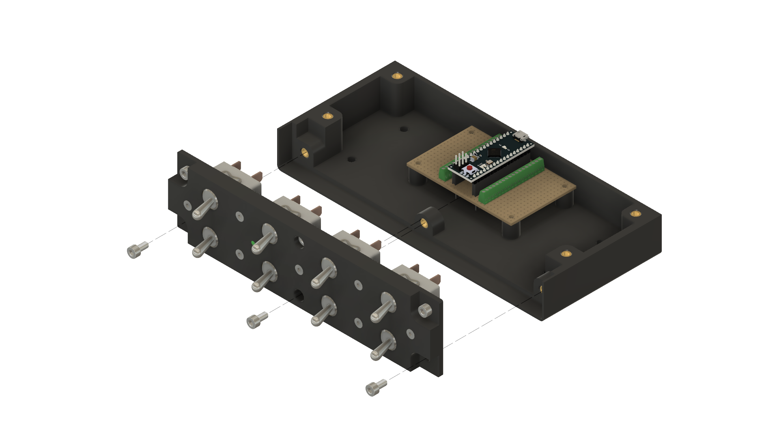
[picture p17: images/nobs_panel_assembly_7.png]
Front plate and mounting plate assembly being secured to the bottom enclosure
  
</p>
<br>

* **Wire Up the Switches:** Following the [wiring map](arduino-esp-32-wiring.md), solder a signal
  wire from each switch terminal to its terminal block position on the controller board, and tie
  all the center (ground) terminals together into a common ground harness.
* **Secure the Assembly:** Fix the front plate / mounting plate assembly to the bottom enclosure
  with its mounting screws.

#### Phase 7: Mount the Top Enclosure

<p align="center">
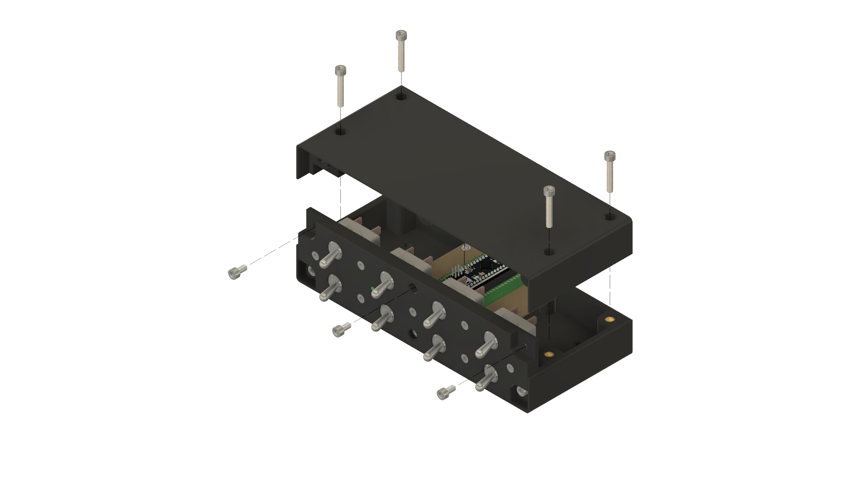
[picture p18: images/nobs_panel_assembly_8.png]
Top enclosure about to be secured over the populated bottom half
  
</p>
<br>

* **Secure Case Shells:** Lower the top enclosure onto the bottom half, making sure no wires are
  pinched, and lock the two shells together with their mounting screws.

#### Phase 8: Finished Panel

<p align="center">
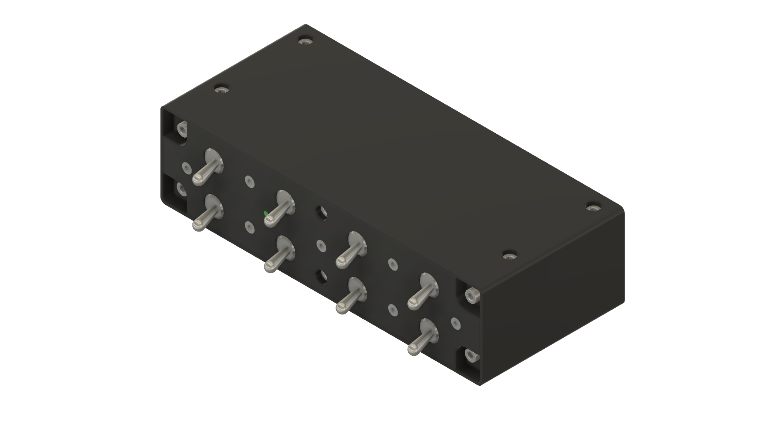
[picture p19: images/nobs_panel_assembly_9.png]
Fully assembled Nobs Panel
  
</p>
<br>

That's a complete, assembled Nobs Panel, ready for the verification steps below.

## Verification & First-Time Setup

1. **Check for shorts first (before plugging in USB):** use a multimeter to make sure none of your
   ground wires are accidentally touching a signal wire. This catches wiring mistakes before they
   reach your PC.
2. **Load the firmware:** follow the [Arduino Nano ESP32 firmware guide](../firmware/arduino_eps32_nano/README.md)
   (for a left mount, use the [left-mount firmware guide](../firmware/arduino_eps32_nano_left/README.md) instead).
3. **Confirm the name:** once plugged in, the panel should show up as `Nobs Panel (Vendor: 303a
   Product: 80f0)`. If it shows a generic name instead, open Windows **Device Manager**, turn on
   **View → Show hidden devices**, uninstall any old listings for the board, and replug it.
4. **Bind it in the sim:** launch MSFS, go to **Options → Control Options**, pick the **Nobs
   Panel** device, and assign each switch position to its desired command.

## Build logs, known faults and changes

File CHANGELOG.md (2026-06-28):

# Changelog

All notable changes to the Nobs Panel project (hardware, firmware, and documentation) are documented in this file.

The format is based on [Keep a Changelog](https://keepachangelog.com/en/1.1.0/),
and this project adheres to [Semantic Versioning](https://semver.org/spec/v2.0.0.html).

## [Unreleased]

### Added
- Build instructions guide ([docs/build-instructions.md](docs/build-instructions.md)): controller-board assembly (stripboard, pin headers, terminal blocks, Arduino Nano ESP32) and enclosure assembly, each step illustrated with a photo.
- Bill of Materials ([docs/bill-of-materials.md](docs/bill-of-materials.md)): core electronics and switches, structural/enclosure hardware, connectors and wiring, plus a per-panel project cost estimate.
- Board identity guide ([docs/board-identity.md](docs/board-identity.md)).
- Arduino Nano ESP32 firmware sketch ([firmware/arduino_eps32_nano/arduino_eps32_nano.ino](firmware/arduino_eps32_nano/arduino_eps32_nano.ino)).
- Left-mount firmware variant ([firmware/arduino_eps32_nano_left/arduino_eps32_nano_left.ino](firmware/arduino_eps32_nano_left/arduino_eps32_nano_left.ino)) and its wiring map ([docs/arduino-esp-32-wiring-left.md](docs/arduino-esp-32-wiring-left.md)), for mounting the panel on the left side of a frame. The map is mirrored for a left mount: the switch order is reversed (SW1/SW2 swap pin groups with SW8/SW7, SW3 with SW6, SW4 with SW5) and each switch's two terminals are swapped so the rotated mount doesn't invert up/down; same 16 buttons as the standard variant. So a left and right panel can share a rig without their MSFS bindings colliding, the left variant defaults to the 2nd panel instance of the PID block (`80F1` / "Nobs Panel 2") instead of `80F0`. Documented in the README "Mounting orientation" section, [docs/board-identity.md](docs/board-identity.md), and cross-linked from the build instructions and standard wiring map.
- Assembly and product photos ([images/](images/)).
- "Design Philosophy" and "Nobs FS Companion App" sections in [README.md](README.md), including a short VR-friendly note (no looking needed to know a switch's state).

### Changed
- Renamed `docs/nobs_panel_wiring_diagram.pdf` to `docs/wiring_diagram.pdf` and updated the links in the README and build instructions.
- Cropped the front-panel product photo ([images/nobs_panel_front.png](images/nobs_panel_front.png)) to remove excess blank canvas above and below the panel.
- Removed em-dash and bare-hyphen sentence connectors and `---` dividers across the docs, in favor of plainer punctuation.

[Unreleased]: https://github.com/ibovegar/nobs-fs-panel/commits/main

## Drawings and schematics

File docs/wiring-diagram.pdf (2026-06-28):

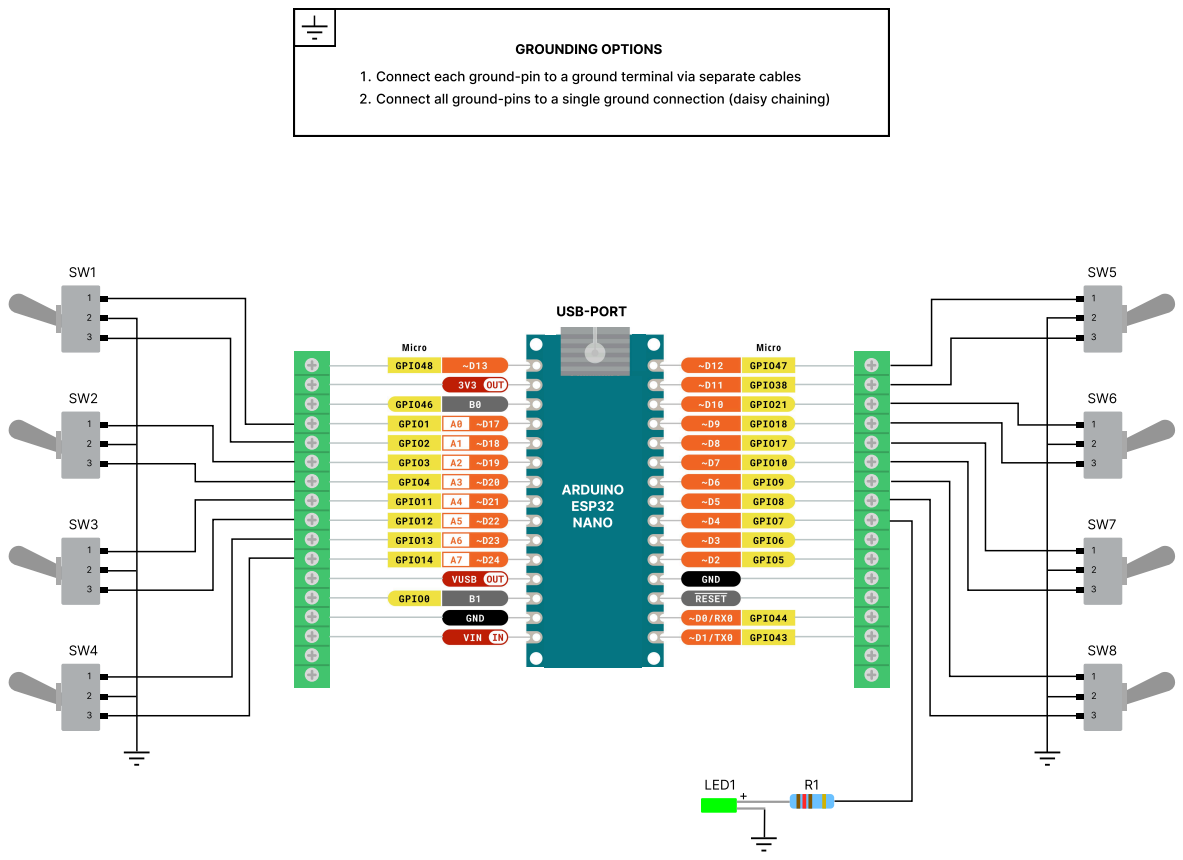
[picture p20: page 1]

Connect each ground-pin to a ground terminal via separate cables
Connect all ground-pins to a single ground connection (daisy chaining)

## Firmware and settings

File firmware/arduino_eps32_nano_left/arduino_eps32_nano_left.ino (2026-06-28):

// Nobs Panel (LEFT-mount variant) — Arduino Nano ESP32 (ESP32-S3) USB HID gamepad firmware.
//
// This is the left-hand-mount sibling of the standard (right-mount) sketch in
// firmware/arduino_eps32_nano/. The two are identical except for the switch-to-pin map,
// which is mirrored so the panel reads correctly when mounted on the *left* side of a
// track-racer T-profile aluminium frame: the switch order is reversed (SW1/SW2 swap pin
// groups with SW8/SW7, SW3 with SW6, SW4 with SW5) AND each switch's two terminals are
// swapped, since the rotated mount also flips every switch's up/down. See
// docs/arduino-esp-32-wiring-left.md for the full button + pin table.
//
// A switch-only sibling of the Nobs Autopilot build, ported to the ESP32-S3's
// native USB. Exposes 16 buttons in the exact order the nobs-fs app expects:
//   buttons 0..15 → 8 toggle switches × 2 outer terminals each
//                   (SW1 Pin1, SW1 Pin3, SW2 Pin1, SW2 Pin3, … SW8 Pin1, SW8 Pin3)
// SW1..SW6 are ON-ON (2-position) and SW7..SW8 are ON-OFF-ON (3-position, the
// center position grounds neither terminal so both buttons read released).
//
// Unlike the Autopilot there are no encoders, so this sketch has no quadrature
// decoding, no acceleration, and no EEPROM acceleration store. Every input is a
// plain switch reported as a held button level.
//
// ── Arduino IDE Tools settings (required) ─────────────────────────────────────
//   Board:        "Arduino Nano ESP32"
//   USB Mode:     "Normal mode (TinyUSB)"     ← the default; needed for custom HID
//   Pin Numbers:  "By Arduino pin (default)"   so D0/A0… match the wiring doc
// No other Tools changes and NO edits to the installed Arduino core are needed — the
// whole USB-identity fix lives in this repo (this sketch + build_opt.h beside it).
//
// ── USB identity: dynamic, stored in NVS (Preferences) ────────────────────────
// The device enumerates with VID 0x303A (Espressif's vendor ID) and a PID + product
// name that are *configurable at runtime*. Each Nobs box gets its own PID so MSFS
// can't mirror/overwrite control bindings across panels. The panel product owns the
// PID block 0x80F0–0x80F3 (instance 1 = 0x80F0 "Nobs Panel", instance 2 = 0x80F1
// "Nobs Panel 2", … see the `panel` entry in the app's device registry,
// src/panel/panel.ts). Because a left panel is meant to share a rig with a standard
// (right) panel, this variant defaults to the *2nd* panel instance, PID 0x80F1 /
// "Nobs Panel 2", so the two never collide out of the box. (If this is your only
// panel, you can move it onto 0x80F0 / "Nobs Panel" with the config app.)
//
// The PID and name live in flash via the native Preferences library (NVS). On boot
// the firmware reads them *before* USB.begin() and applies them to the descriptor.
// The configuration/diagnostic app can change them over the USB CDC serial port:
//
//   "SET_ID:<pidHex>:<name>\n"  store PID (hex, e.g. 80F0) + product name to NVS,
//                               then soft-reboot so the new identity takes effect
//   "GET_ID\n"                  reply "ID:<pidHex>:<name>" with the stored values
//
// After SET_ID the firmware replies "OK:<pidHex>:<name>", flushes, and calls
// ESP.restart(); the host re-enumerates the device under its new profile. (Identity
// can't change live mid-session because the USB stack is brought up once at boot.)
//
// This NVS-at-boot scheme works because the Nano ESP32 normally forces "USB CDC On
// Boot" and "DFU On Boot" on, which would make the core bring USB up at boot (before
// setup()), freezing the descriptor with the stock 0x2341/0x0070 identity. The
// build_opt.h file next to this sketch overrides both to 0 (it is appended to every
// compile, including the core's), so the boot-time USB.begin() is skipped and our
// runtime identity wins. With CDC-on-boot off, the core's `Serial` is the hardware
// UART, so the app's config port is our own USB CDC interface (USBSerial below).
//
// Re-flashing: the running firmware reports a custom PID (and, with DFU-on-boot off, no
// DFU runtime interface), so the IDE can't auto-enter the bootloader. Double-tap the
// RESET button (RGB LED pulses) before uploading. See this folder's README.md.

#include "USB.h"
#include "USBHID.h"
#include "USBCDC.h"
#include <Preferences.h>

#if ARDUINO_USB_MODE
#error "Set Tools > USB Mode to 'Normal mode (TinyUSB)'. Custom HID needs the TinyUSB stack."
#endif
#if ARDUINO_USB_CDC_ON_BOOT
#error "build_opt.h is not taking effect: ARDUINO_USB_CDC_ON_BOOT must be 0. Make sure build_opt.h sits next to this .ino (it disables CDC/DFU-on-boot so the runtime USB identity works)."
#endif

// ── Custom HID gamepad: 16 buttons, no axes ───────────────────────────────────
// 16 1-bit buttons pack exactly into a flat 2-byte report (no padding bits needed).
// The same 16 bits are also declared as a Feature report so a host can pull the
// current state on demand (GET_REPORT(Feature)) the moment it opens the device —
// see _onGetFeature. The Feature item reuses the global Report Size/Count set for
// the Input item; only the (local) button usages are re-declared.
static const uint8_t HID_REPORT_DESCRIPTOR[] = {
  0x05, 0x01,        // Usage Page (Generic Desktop)
  0x09, 0x05,        // Usage (Game Pad)
  0xA1, 0x01,        // Collection (Application)
  0x05, 0x09,        //   Usage Page (Button)
  0x19, 0x01,        //   Usage Minimum (Button 1)
  0x29, 0x10,        //   Usage Maximum (Button 16)
  0x15, 0x00,        //   Logical Minimum (0)
  0x25, 0x01,        //   Logical Maximum (1)
  0x75, 0x01,        //   Report Size (1)
  0x95, 0x10,        //   Report Count (16)
  0x81, 0x02,        //   Input (Data,Var,Abs)
  0x19, 0x01,        //   Usage Minimum (Button 1)   — re-declared for the Feature item
  0x29, 0x10,        //   Usage Maximum (Button 16)
  0xB1, 0x02,        //   Feature (Data,Var,Abs)     — same 16 bits, host-readable on demand
  0xC0               // End Collection
};

class NobsGamepad : public USBHIDDevice {
public:
  NobsGamepad() { HID.addDevice(this, sizeof(HID_REPORT_DESCRIPTOR)); }

  void begin() { HID.begin(); }

  // Set/clear one button bit in the pending report (mirrors Joystick.setButton).
  void setButton(uint8_t index, uint8_t value) {
    if (index >= 16) return;
    uint8_t byteIdx = index >> 3;
    uint8_t mask    = 1 << (index & 7);
    if (value) report[byteIdx] |= mask;
    else       report[byteIdx] &= ~mask;
  }

  // One USB report carrying every button change since the last call (mirrors
  // Joystick.sendState). Only transmitted when something actually changed — HID
  // hosts track button state edge-to-edge, so re-sending identical reports just
  // adds USB traffic and risks blocking the loop.
  void sendState() {
    if (memcmp(report, lastSent, sizeof(report)) == 0) return;
    if (HID.SendReport(0, report, sizeof(report))) {
      memcpy(lastSent, report, sizeof(report));
    }
  }

  // Re-publish the current report even when nothing changed. The initial report
  // is only emitted once (on the first change after boot), so a host that opens
  // the device later misses it and can't know the resting switch positions until
  // the user moves something. loop() calls this on a slow heartbeat so any host
  // re-syncs the true state within the heartbeat interval.
  void resend() {
    if (HID.SendReport(0, report, sizeof(report))) {
      memcpy(lastSent, report, sizeof(report));
    }
  }

  // USBHIDDevice: hand the descriptor to the core during enumeration.
  uint16_t _onGetDescriptor(uint8_t* buffer) override {
    memcpy(buffer, HID_REPORT_DESCRIPTOR, sizeof(HID_REPORT_DESCRIPTOR));
    return sizeof(HID_REPORT_DESCRIPTOR);
  }

  // Answer GET_REPORT(Feature) with the current button state. This lets a host
  // read the resting switch positions the instant it opens the device, instead of
  // waiting for the heartbeat or a user actuation. (The ESP32 USB stack routes
  // feature get-reports here but STALLs input get-reports, so on-demand state is
  // exposed as a Feature report mirroring the Input report's 16 button bits.)
  uint16_t _onGetFeature(uint8_t report_id, uint8_t* buffer, uint16_t len) override {
    (void)report_id; // single unnumbered report
    if (len < sizeof(report)) return 0;
    memcpy(buffer, report, sizeof(report));
    return sizeof(report);
  }

private:
  USBHID  HID;
  uint8_t report[2]   = { 0, 0 };
  uint8_t lastSent[2] = { 0xFF, 0xFF }; // force the first real report out
};

NobsGamepad Joystick;

// USB CDC config port. With CDC-on-boot disabled (via build_opt.h) the core's `Serial`
// is the hardware UART, so we expose our own USB CDC interface for the config app.
// Like USBHID, USBCDC registers its interface in its constructor (static init), so it
// is in place before USB.begin() builds the composite descriptor in setup().
USBCDC USBSerial;

// ── Dynamic USB identity (NVS via Preferences) ────────────────────────────────
// VID is fixed (Espressif's vendor ID); PID + product name are stored in flash and
// host-configurable. Defaults are the panel profile; an unconfigured chip uses them.
// NB: named NOBS_USB_VID, not USB_VID — the core's pins_arduino.h #defines USB_VID.
const uint16_t NOBS_USB_VID    = 0x303A;
const uint16_t DEFAULT_PID     = 0x80F1;        // 2nd panel instance (left mount)
const char*    DEFAULT_NAME    = "Nobs Panel 2";
const char*    NVS_NAMESPACE   = "nobs";
const char*    NVS_KEY_PID     = "pid";
const char*    NVS_KEY_NAME    = "name";

Preferences prefs;
uint16_t     usbPid;     // active PID (kept alive for the whole session)
String       usbName;    // active product name (c_str() must outlive USB.begin())

void loadIdentity() {
  prefs.begin(NVS_NAMESPACE, true); // read-only
  usbPid  = prefs.getUShort(NVS_KEY_PID, DEFAULT_PID);
  usbName = prefs.getString(NVS_KEY_NAME, DEFAULT_NAME);
  prefs.end();
}

void storeIdentity(uint16_t pid, const String& name) {
  prefs.begin(NVS_NAMESPACE, false); // read-write
  prefs.putUShort(NVS_KEY_PID, pid);
  prefs.putString(NVS_KEY_NAME, name);
  prefs.end();
}

// ── USB string descriptors: name the interfaces after the product ─────────────
// The core hardcodes the HID/CDC *interface* strings to "TinyUSB HID"/"TinyUSB CDC".
// For a composite device (HID + CDC) Windows and MSFS show that interface string as
// the controller's name — so without this the panel shows up as "TinyUSB HID" even
// though iProduct is "Nobs Panel". tud_descriptor_string_cb is weak in the core, so
// defining it here replaces it (no core edit needed) and points every interface
// string at the product name. Index map: 0=language, 1=manufacturer, 2=product,
// 3=serial (from the chip MAC, stable per board), 4+=interface strings → product.
extern "C" const uint16_t* tud_descriptor_string_cb(uint8_t index, uint16_t langid) {
  (void)langid;
  static uint16_t desc[40];

  if (index == 0) {
    desc[1] = 0x0409; // English (United States)
    desc[0] = (uint16_t)((3 << 8) | (2 * 1 + 2));
    return desc;
  }
  // Beyond our real strings (1..3 + a handful of interface strings). Returning NULL
  // mirrors the core and lets Windows' MS-OS probe at index 0xEE fail cleanly.
  if (index >= 16) return NULL;

  char serial[16];
  const char* str;
  switch (index) {
    case 1: str = "Arduino"; break;       // manufacturer (matches USB.manufacturerName)
    case 2: str = usbName.c_str(); break; // product (iProduct)
    case 3:                               // serial — stable per board
      snprintf(serial, sizeof(serial), "%012llX", (unsigned long long)ESP.getEfuseMac());
      str = serial;
      break;
    default: str = usbName.c_str(); break; // HID/CDC/config interface strings
  }

  uint8_t chr_count = strlen(str);
  if (chr_count > 38) chr_count = 38; // desc holds 39 UTF-16 chars + the header word
  for (uint8_t i = 0; i < chr_count; i++) desc[1 + i] = str[i];
  desc[0] = (uint16_t)((3 << 8) | (2 * chr_count + 2));
  return desc;
}

// ── Pin assignments (Arduino Nano ESP32 labels — see arduino-esp-32-wiring-left.md) ─
// LEFT-mount variant. In HID button order: button i is driven by swPin[i]. Each switch
// contributes two consecutive buttons; the center terminal is GND. The panel is mirrored
// for a left mount, which changes the standard (right-mount) map in two ways:
//   (1) the switch ORDER is reversed — SW1/SW2 swap pin groups with SW8/SW7, and the
//       middle four mirror too (SW3 with SW6, SW4 with SW5);
//   (2) each switch sits rotated, so its two positions are flipped — the firmware lists
//       each switch's Pin 3 terminal first (Position 1) and Pin 1 second (Position 2),
//       which undoes the up/down inversion (flipping a switch up reads as up).
// The app maps every HID button to a fixed switch label, so this is what makes the panel
// read the right way around (e.g. flipping SW3 up shows up as SW3, up).
//
//   index  HID button  switch / terminal   pin
//   0      Button 1     SW1 Pin 3           D7
//   1      Button 2     SW1 Pin 1           D8
//   2      Button 3     SW2 Pin 3           D5
//   3      Button 4     SW2 Pin 1           D6
//   4      Button 5     SW3 Pin 3           D9
//   5      Button 6     SW3 Pin 1           D10
//   6      Button 7     SW4 Pin 3           D11
//   7      Button 8     SW4 Pin 1           D12
//   8      Button 9     SW5 Pin 3           A7
//   9      Button 10    SW5 Pin 1           A6
//   10     Button 11    SW6 Pin 3           A5
//   11     Button 12    SW6 Pin 1           A4
//   12     Button 13    SW7 Pin 3           A3
//   13     Button 14    SW7 Pin 1           A2
//   14     Button 15    SW8 Pin 3           A1
//   15     Button 16    SW8 Pin 1           A0
const uint8_t swPin[16] = {
  D7,  D8,  D5,  D6,  D9,  D10, D11, D12,
  A7,  A6,  A5,  A4,  A3,  A2,  A1,  A0,
};

// NOTE: every pin above is driven with INPUT_PULLUP, so the closed-to-GND wiring
// reads LOW = pressed. All of these GPIOs support the ESP32-S3 internal pull-up;
// if a future revision moves a signal onto a pull-up-less pad, add an external
// 10 kΩ pull-up to 3V3 there.

// ── Status LED (D4) ────────────────────────────────────────────────────────────
// Blinks while booting/waiting for USB enumeration, steady once enumerated. D4 also
// doubles as DSR (a USB CDC modem-control signal), but this sketch never drives DSR,
// so the pin is free for plain GPIO use.
const uint8_t STATUS_LED_PIN = D4;

// ── Host serial config ───────────────────────────────────────────────────────
// Line protocol over the USB CDC port (see header). SET_ID persists a new identity
// to NVS and reboots; GET_ID reports the current one.
char    cmdBuf[64];
uint8_t cmdLen = 0;

void printIdentity(const char* prefix) {
  char pidHex[5];
  snprintf(pidHex, sizeof(pidHex), "%04X", usbPid);
  USBSerial.print(prefix);
  USBSerial.print(':');
  USBSerial.print(pidHex);
  USBSerial.print(':');
  USBSerial.println(usbName);
}

void applyConfigCommand(const char* s) {
  if (strcmp(s, "GET_ID") == 0) {
    printIdentity("ID");
    return;
  }
  if (strncmp(s, "SET_ID:", 7) != 0) return;

  const char* p     = s + 7;          // "<pidHex>:<name>"
  const char* colon = strchr(p, ':');
  if (!colon || colon == p) return;   // need a PID and a separator

  char pidStr[8] = { 0 };
  size_t n = colon - p;
  if (n >= sizeof(pidStr)) return;
  memcpy(pidStr, p, n);
  uint16_t pid = (uint16_t)strtol(pidStr, nullptr, 16);

  String name = colon + 1;            // everything after the second ':'
  name.trim();
  if (name.length() == 0) return;

  storeIdentity(pid, name);
  // Reflect the just-stored values, confirm, then reboot so USB re-enumerates.
  usbPid  = pid;
  usbName = name;
  printIdentity("OK");
  USBSerial.flush();
  delay(50);                          // let the CDC packet drain before reset
  ESP.restart();
}

void handleSerialConfig() {
  while (USBSerial.available()) {
    char c = USBSerial.read();
    if (c == '\n' || c == '\r') {
      cmdBuf[cmdLen] = '\0';
      if (cmdLen > 0) applyConfigCommand(cmdBuf);
      cmdLen = 0;
    } else if (cmdLen < sizeof(cmdBuf) - 1) {
      cmdBuf[cmdLen++] = c;
    } else {
      cmdLen = 0; // overlong line (no newline) — drop it and resync
    }
  }
}

// ── USB enumeration tracking (for the status LED) ─────────────────────────────
// This device is read purely over HID for normal use — the CDC port is only ever
// opened for one-off config, so it can't tell us whether the flight-sim app is
// actually using the device. The best available signal is USB enumeration itself:
// ARDUINO_USB_STARTED_EVENT fires once the host finishes recognizing the composite
// device (tud_mount_cb), ARDUINO_USB_STOPPED_EVENT if it's unplugged or the bus
// drops (tud_umount_cb). So "connected" here means "enumerated by a host", not "the
// app has it open" — there's no such signal for a plain HID gamepad with no
// application-level handshake.
volatile bool hostConnected = false;

void onUsbEvent(void* arg, esp_event_base_t base, int32_t id, void* eventData) {
  (void)arg;
  (void)base;
  (void)eventData;
  if (id == ARDUINO_USB_STARTED_EVENT) hostConnected = true;
  else if (id == ARDUINO_USB_STOPPED_EVENT) hostConnected = false;
}

// Blink while booting/waiting for USB enumeration; steady once enumerated
// (hostConnected, set from the USB started/stopped events above). Non-blocking so it
// never stalls loop().
void updateStatusLed() {
  if (hostConnected) {
    digitalWrite(STATUS_LED_PIN, HIGH);
    return;
  }
  static uint32_t lastToggle = 0;
  static bool     ledOn      = false;
  uint32_t now = millis();
  if (now - lastToggle >= 150) {
    lastToggle = now;
    ledOn = !ledOn;
    digitalWrite(STATUS_LED_PIN, ledOn);
  }
}

void setup() {
  for (uint8_t i = 0; i < 16; i++) {
    pinMode(swPin[i], INPUT_PULLUP);
  }
  pinMode(STATUS_LED_PIN, OUTPUT);

  // Load the saved identity (PID + name) from NVS, falling back to the panel
  // defaults on a fresh chip.
  loadIdentity();

  // USB identity — set BEFORE USB.begin() so the descriptor is built with the stored
  // VID/PID/name. This works because build_opt.h disabled CDC/DFU-on-boot, so USB has
  // NOT been started yet.
  USB.VID(NOBS_USB_VID);
  USB.PID(usbPid);
  USB.productName(usbName.c_str());
  USB.manufacturerName("Arduino");

  Joystick.begin();        // create the HID report semaphores/mutex
  USB.onEvent(onUsbEvent); // detect USB enumeration, for the status LED
  USBSerial.begin(115200); // USB CDC config port; do NOT wait on it (would stall)
  USB.begin();             // build + start the composite USB device (HID + CDC)
}

void loop() {
  handleSerialConfig(); // apply any pending SET_ID/GET_ID command
  updateStatusLed();    // blink while waiting for USB enumeration, steady once enumerated

  // Each switch terminal is reported as a held level (pressed = LOW with INPUT_PULLUP).
  for (uint8_t i = 0; i < 16; i++) {
    Joystick.setButton(i, digitalRead(swPin[i]) == LOW ? 1 : 0);
  }

  // One USB report with all the updates above (sent only when changed).
  Joystick.sendState();

  // Heartbeat: re-publish the current state periodically so a host that opens the
  // device after boot (missing the one initial report) picks up the resting switch
  // positions without the user having to move anything. 250 ms is imperceptible
  // yet negligible USB traffic (2 bytes, ~4×/s).
  static uint32_t lastBeat = 0;
  uint32_t now = millis();
  if (now - lastBeat >= 250) {
    lastBeat = now;
    Joystick.resend();
  }
}

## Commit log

2026-06-13 Add models
    [enclosure_bottom.step, enclosure_top.step, nobs_panel_frontpanel.step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]
2026-06-18 Fix heat insert issue
    [enclosure_bottom.step, enclosure_top.step, nobs_panel_mounting_plate.step]
2026-06-20 Update modelks and add wiring diagram
2026-06-20 Update models
    [enclosure_bottom.step, enclosure_top.step, nobs_panel_frontpanel.step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]
2026-06-22 Add build instructions, BOM, board identity, and firmware docs
    Documents the full build: a step-by-step assembly guide with photos,
    a bill of materials with a cost estimate, the board-identity/rename
    workflow, and the Arduino Nano ESP32 firmware sketch. Also tidies up
    README.md (design philosophy, companion app section, VR note) and
    fixes the wiring-diagram link after its PDF was renamed.
    [arduino_eps32_nano.ino]
2026-06-28 Update frontplate model
    [nobs_panel_frontpanel.step]
2026-06-28 Add left-mount firmware variant and status LED
    Left-mount variant for mounting the panel on the left side of a frame:
    - New firmware (firmware/arduino_eps32_nano_left/) and wiring map
    (docs/arduino-esp-32-wiring-left.md). The pin map is mirrored: the
    switch order is reversed (SW1/SW2 swap pin groups with SW8/SW7, SW3
    with SW6, SW4 with SW5) and each switch's two terminals are swapped so
    the rotated mount doesn't invert up/down.
    - Defaults to the 2nd panel instance of the PID block (80F1 / "Nobs
    Panel 2") so a left + right pair can share a rig without their MSFS
    bindings colliding.
    - Documented in the README "Mounting orientation" section, board
    identity guide, and cross-linked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
    [arduino_eps32_nano_left.ino]
2026-07-01 Add product image to README, fix wiring diagram link typo
2026-07-02 Document rig mounting layout and add assembly image
    Shows how Nobs Panel, Approach, and Autopilot mount together on a
    T-slot rig around the central yoke/wheel assembly.
2026-11-02 Add wiring diagram as SVG and HTML
    The same pins and layout as the existing wiring doc, drawn with each
    control beside the header pins it connects to. The SVG is on a white
    background; the HTML page follows the light/dark theme.
2026-11-02 Add status-LED timeout and USB hand-over fix; ship models as STL
    - Firmware (standard and left mount): stop blinking the status LED after
    10 s without a host, and drop the D+ pull-up briefly before USB.begin()
    so a cold plug-in enumerates the Nobs device instead of the boot-time
    303A:1001 one. The wiring docs describe the LED timeout.
    - Models: replace the STEP files with STL; ignore slicer .3mf files.
